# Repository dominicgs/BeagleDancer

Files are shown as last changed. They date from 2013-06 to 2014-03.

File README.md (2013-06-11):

BeagleDancer
============

A Facedancer expansion board for the BeagleBone.  Most of the hard work was
done by Travis Goodspeed and Philippe Teuwen.  You can find their projects at
http://goodfet.sf.net and http://wiki.yobi.be/wiki/Raspdancer.

It's called "BeagleDancer" because it sounded better than "FaceBone".

Pins (Beagle name)
------------------
- 1) GND
- 3) 3.3V
- 5) 5V
- 11) USB OTG ID detect (UART4_RXD - gpio0[30])
- 13) Interrupt (UART4_TXD - gpio0[31])
- 15) GPX (GPIO1_16 - gpio1[16])
- 17) SPI0_CS0 (I2C1_SCL)
- 18) SPI0_D1 (I2C1_SDA)
- 21) SPI0_D0 (UART2_TXD)
- 22) SPI0_SCLK (UART2_RXD)
- 23) Reset (GPIO1_17 - gpio1[17])

Software
--------
These instructions have been tested ona  Debian image for the BeagleBone Black,
the image can be found on the eLinux site:
http://elinux.org/BeagleBoardDebian#Flasher

First install the prerequisites:
 $ apt-get install gcc make python-dev python-serial
 
Seconly, configure the pin multiplexes to allow access to the SPI device from
the operating system.  Detailed instructions are given in devicetree/README.md
You may want to add a udev rule to allow non-root access to the SPI device.

The next step is to download and build the SPI-Py module (GPL), it can be found
at https://github.com/lthiery/SPI-Py

Build instructions are as follows:
- $ git clone git://github.com/lthiery/SPI-Py.git
- $ cd SPI-Py
- $ python setup.py build
- $ sudo python setup.py install

Finally, we need to reset the MAX3421 chip using GPIO1_17.  As root:
- $ echo "48" > /sys/class/gpio/export
- $ echo "49" > /sys/class/gpio/export
- $ echo "30" > /sys/class/gpio/export
- $ echo "31" > /sys/class/gpio/export
- $ echo "out" > /sys/class/gpio/gpio49/direction
- $ echo "0" > /sys/class/gpio/gpio49/value
- $ echo "1" > /sys/class/gpio/gpio49/value

Licensing, etc
--------------
Copyright 2013 Dominic Spill <dominicgs@gmail.com>.

This program is free software; you can redistribute it and/or modify it under
the terms of the GNU General Public License V2 as published by the Free Software
Foundation.

Liability
---------
This program is distributed for educational purposes only and is no way suitable
for any particular application, especially commercial. There is no implied
suitability so use at your own risk!

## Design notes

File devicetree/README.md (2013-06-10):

DeviceTree
==========

When running Linux, the BeagleBones use devicetree to manage multiplexed pins.
Lots of very useful information on configurning devicetree for the BeagleBone
can be found on either of these blogs:
- http://blog.inbedded.net
- http://hipstercircuits.com

Many thanks go to Christophe Aeschlimann (inbedded.net) for sample code and a 
conveniently patched dtc, and to Elias Bakken (hipstercircuits.com) for taking
the trouble to find and document the pinmux descriptions and offsets.

Building
--------
The two config files should be compiled with a copy of device-tree-compiler
which has been modified to accet the @ (overload) option.  The source for dtc
can be found in the scripts/dtc directory of the Linux kernel source and the
patch can be found at:
https://github.com/RobertCNelson/linux-dev/blob/am33x-v3.8/patches/not-capebus/0019-dtc-Dynamic-symbols-fixup-support.patch

Compile with the following commandline options:
- $./dtc -O dtb -o am335x-boneblack.dtb -b 0 -@ am335x-boneblack.dts
- $./dtc -O dtb -o cape-beagledance-00A0.dtbo -b 0 -@ cape-beagledancer-00A0.dts

The file is named "cape-beagledance-00A0.dtbo" (without the trailing 'r') 
because the there is an nine character limit on the cape name.

Alternatively, the binary files (am335x-boneblack.dtb, cape-beagledance-00A0.dtbo)
are included in this repository, although they are not guaranteed to be up to
date.

Usage
-----
The files should be placed in to /boot/uboot/dtbs and /lib/firmware as shown:
- $ cp am335x-boneblack.dtb /boot/uboot/dtbs/
- $ cp cape-beagledance-00A0.dtbo /lib/firmware/

Then reboot the BeagleBone so that the am335x-boneblack setting take effect.

Once rebooted, run the following as root:
 $ echo "cape-beagledancer " > /sys/devices/bone_capemgr.9/slots

You should now see "spidev1.0" in /dev.  This has been tested on debian but the
process should be similar for other distributions.

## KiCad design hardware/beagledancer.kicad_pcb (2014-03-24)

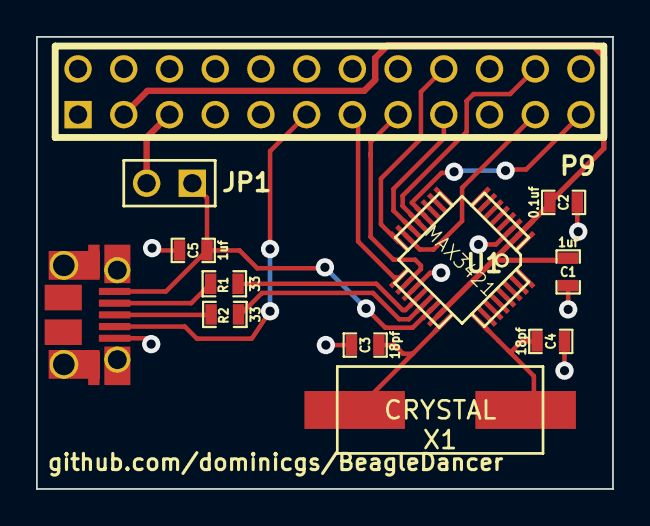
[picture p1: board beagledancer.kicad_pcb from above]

Board: 2 copper layers, 32.0 x 25.1 mm, 12 parts (0 on the bottom side), 18 nets.

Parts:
C1, C5: 1uf; SM0603_Capa
C2: 0.1uf; SM0603_Capa
C3, C4: 18pf; SM0603_Capa
J1: USB-MICRO-B; GSG-USB-MICROB-FCI-10103594
JP1: JUMPER; PIN_ARRAY_2X1
P9: BeagleBone; pin_array_12x2
R1, R2: 33; SM0603_Resistor
U1: MAX3421
X1: CRYSTAL; HC49-US

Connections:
+3.3V: C1.1, C2.1, P9.3, U1.2, U1.23
+5V: JP1.2, P9.5
/D+: R2.1, U1.21
/D-: R1.1, U1.20
/RES: P9.23, U1.12
/VBCOMP: C5.1, J1.1, JP1.1, U1.22
/XI: C3.1, U1.24, X1.1
/XO: C4.1, U1.25, X1.2
GND: C1.2, C2.2, C3.2, C4.2, C5.2, J1.5, P9.1, U1.3, U1.19
GPX: P9.13, U1.17
INT: P9.15, U1.18
unnamed: J1.2, R1.2
unnamed: J1.3, R2.2
SPI0_CS0: P9.17, U1.14
SPI0_D0: P9.21, U1.15
SPI0_D1: P9.18, U1.16
SPI0_SCLK: P9.22, U1.13
USB_ID: J1.4, P9.11

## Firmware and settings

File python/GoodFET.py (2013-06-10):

#!/usr/bin/env python
# (C) 2013 Philippe Teuwen <phil at teuwen.org>
# (C) 2013 Dominic Spill <dominicgs@gmail.com>
 
# Ok, I need to fix the GPIO handling before this really counts as "working"!
import spi
#import RPi.GPIO as GPIO
 
class GoodFET:
    data=""
    def __init__(self, *args, **kargs):
#        GPIO.setmode(GPIO.BOARD)
#        # pin15=GPIO22 is linked to MAX3420 -RST
#        GPIO.setup(15, GPIO.OUT)
#        GPIO.output(15,GPIO.LOW)
#        GPIO.output(15,GPIO.HIGH)
        spi.openSPI(device="/dev/spidev1.0", speed=26000000)
    def __del__(self):
        spi.closeSPI()
#        GPIO.output(15,GPIO.LOW)
#        GPIO.output(15,GPIO.HIGH)
#        GPIO.cleanup()
    def writecmd(self, app, verb, count=0, data=[]):
        if verb: # ignore all but R/W cmd
            return
        if isinstance(data,str):
            data = [ord(x) for x in data]
        data = tuple(data)
        data = spi.transfer(data)
        self.data = "".join([chr(x) for x in data])
    def serInit(self):
        pass

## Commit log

2013-05-10 Initial commit of BeagleDancer design.
    [beagledancer.kicad_pcb, beagledancer.sch]
2013-05-11 Update based on feedback from Michael Ossmann (mossmann)
    [beagledancer.kicad_pcb, beagledancer.sch]
2013-05-11 Tweak layout to detect OTG pin status with GPIO pin
    [beagledancer.kicad_pcb, beagledancer.sch]
2013-05-11 More feedback
    [beagledancer.kicad_pcb]
2013-05-11 Connect INT and GPX to GPIO pins on the Beagle.
    [beagledancer.kicad_pcb, beagledancer.sch]
2013-05-12 Fix MAX3421 size
    [beagledancer.kicad_pcb, beagledancer.sch]
2013-05-12 Tidy up 5V and 3.3V traces.
    [beagledancer.kicad_pcb]
2013-05-12 Use bigger pads for the MAX3421 - as per land pattern.
    [beagledancer.kicad_pcb]
2013-05-12 Swap C1/C2 to correct positions on schematic, named nets, ether tweaks.
    [beagledancer.kicad_pcb, beagledancer.sch]
2013-05-13 Add labels to silkscreen
    [beagledancer.kicad_pcb]
2013-05-13 Adjust GND zone thermal relief to remove gaps around pin 1 of P9.
    [beagledancer.kicad_pcb]
2013-05-14 Add part details to BOM.
    [beagledancer.sch]
2013-05-14 Add USB connector to BOM.
    [beagledancer.sch]
2013-06-09 Rearrange to add software portion of project
    [beagledancer.kicad_pcb, beagledancer.sch]
2013-06-10 Device tree config to get spidev1.0 working
2013-06-10 Working SPI and GPIO instructions
2014-03-24 Change crystal to match FaceDancer
    [beagledancer.kicad_pcb, beagledancer.sch]
2014-03-24 Some minor tweaks to make everything fit properly.
    [beagledancer.kicad_pcb]

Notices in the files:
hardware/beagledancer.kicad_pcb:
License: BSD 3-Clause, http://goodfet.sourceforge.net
